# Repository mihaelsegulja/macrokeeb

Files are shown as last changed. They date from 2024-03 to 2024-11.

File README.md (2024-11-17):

# macrokeeb

Simple 10-key Arduino-based macropad with OLED screen and rotary encoder I did for my high school final project.

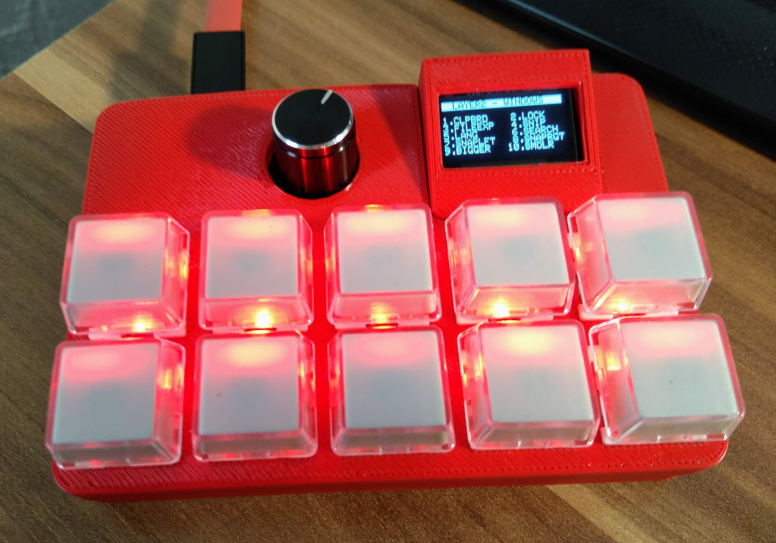
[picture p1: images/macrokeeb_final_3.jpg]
macrokeeb


## Features

- 10 programmable keys
- 5 layers/modes (General, Windows, Linux, VSCode, Other) which can be switched by pressing the button on the rotary encoder
- Rotary encoder knob changes the audio volume
- OLED screen shows current layer and its predefined macros

## Parts

- 1x Arduino Pro Micro
- 1x I2C OLED display, 128x64, 0.96 inch
- 1x Rotary encoder KY-040
- 10x Mechanical switches, red (any Cherry MX compatible will do)
- 10x Keycaps (any Cherry MX compatible will do)
- 10x Standard signal diodes 1N4148
- 10x LED lights, red, 3mm
- Wires (reused from old Christmas lights)
- 3D printed case

### Tools

- 3D printer
- Soldering iron and solder
- Wire cutters
- Hot glue gun
- Sandpaper

## Case

I used the following and modified it a bit (removed the logo, added hex mesh on the side, added hole...):
[CODEK - Configurable OLED Display Extension Keyboard](https://www.thingiverse.com/thing:4539723)

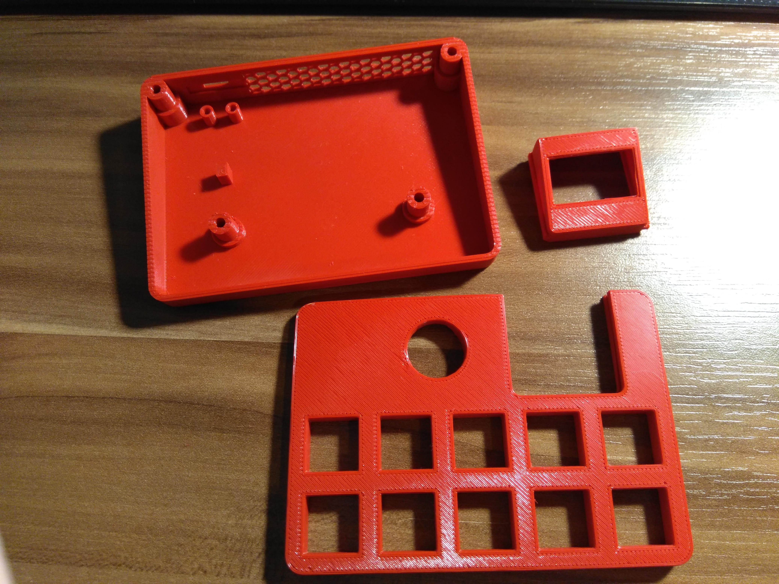
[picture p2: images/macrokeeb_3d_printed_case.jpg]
case


> [!TIP]
> Use sandpaper to smoothen rough edges, read more [here](https://www.3dsourced.com/guides/sanding-pla/) on how to do it.

## Assembly

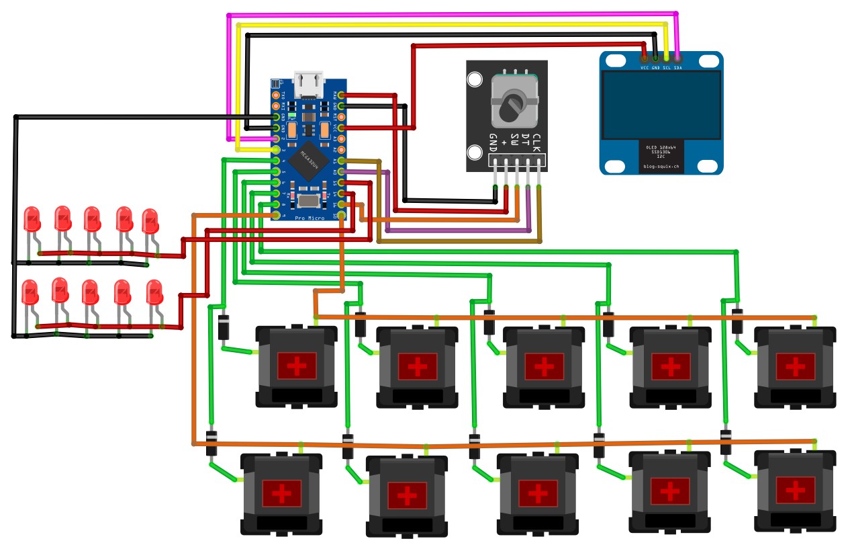
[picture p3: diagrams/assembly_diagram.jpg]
diagram1


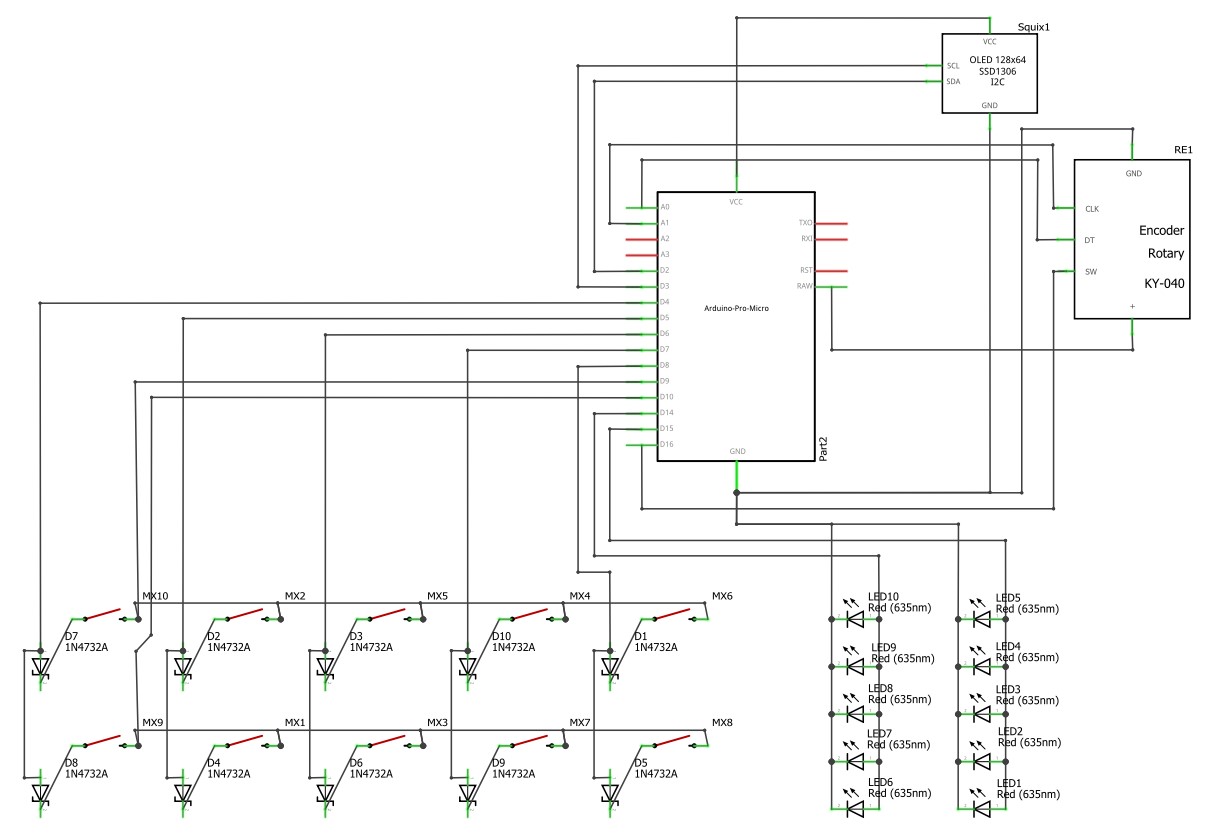
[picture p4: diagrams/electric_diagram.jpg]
diagram2


> [!TIP]
> Before putting it all together, test all of your components separately to ensure they all work.

### Steps

1. Slide the OLED display holder into the top plate. Install the switches into the top plate. Both can be a tight fit, but that shouldn't be a problem. In that case, apply more pressure or sand down the tight parts.

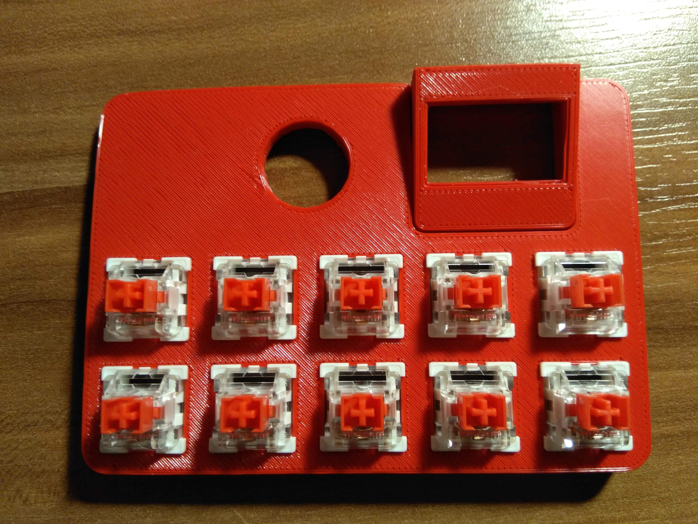
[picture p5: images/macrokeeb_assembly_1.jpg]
step1


2. For wiring, refer to the diagrams. Basically, you have to wire the keys in a matrix. For soldering, I suggest one the following: 
 - cut the wires in smaller ones, long enough to wire up one switch with the next one, 
 - use one wire per row/column and remove the coating where needed,
 - use one wire per row/column and solder through the coating

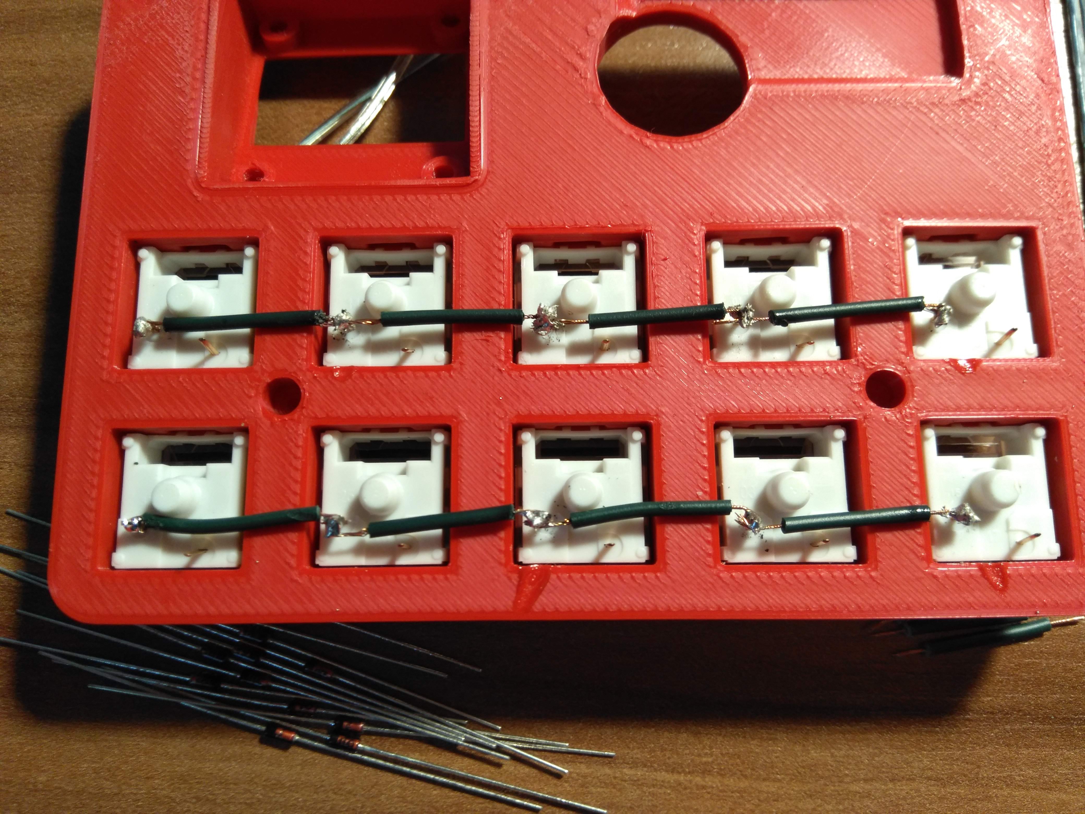
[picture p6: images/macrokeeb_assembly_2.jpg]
step2


3. Add signal diodes on all the keys, it will ensure that the microcotroller doesn't read key presses wrong when pressing several keys at once.

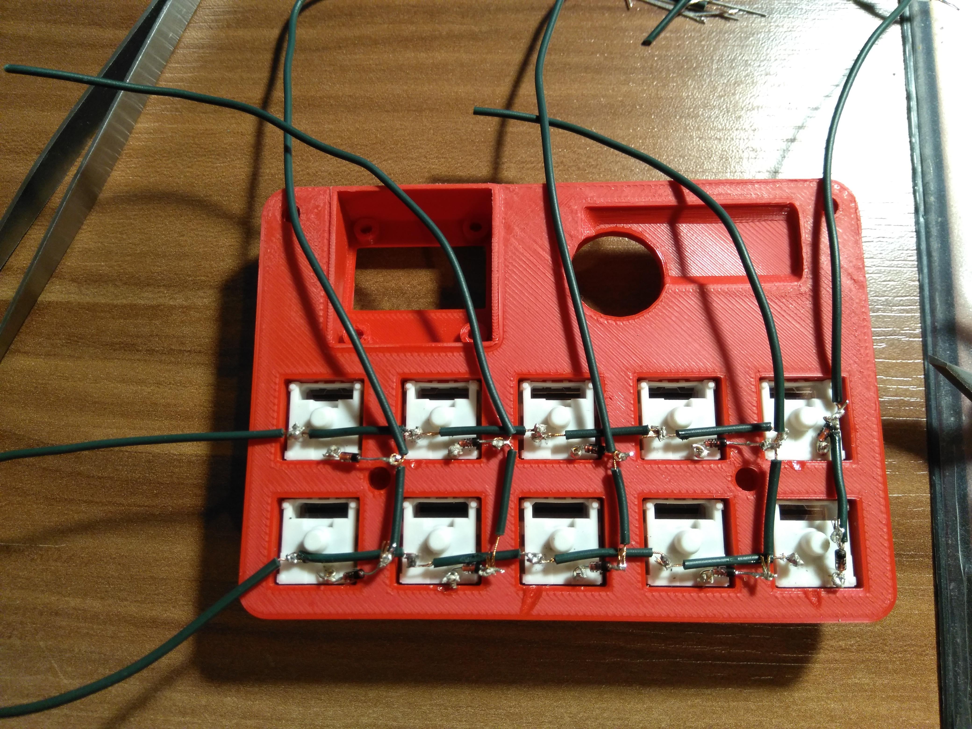
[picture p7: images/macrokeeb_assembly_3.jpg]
step3


4. Adding LEDs is purely for aesthetics.

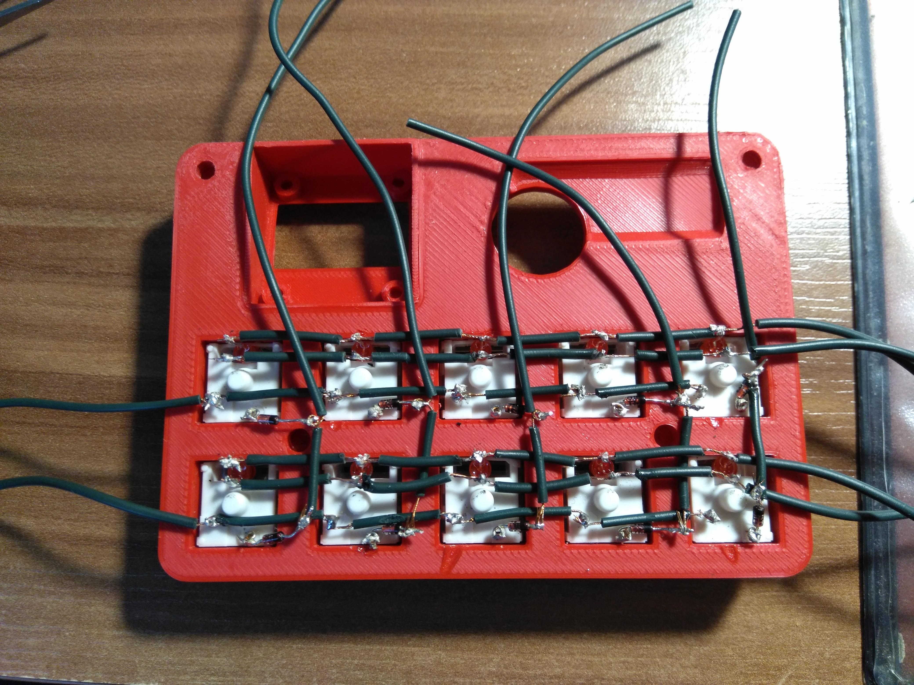
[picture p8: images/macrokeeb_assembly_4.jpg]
step4


5. Solder wires to the OLED display and rotary encoder too.

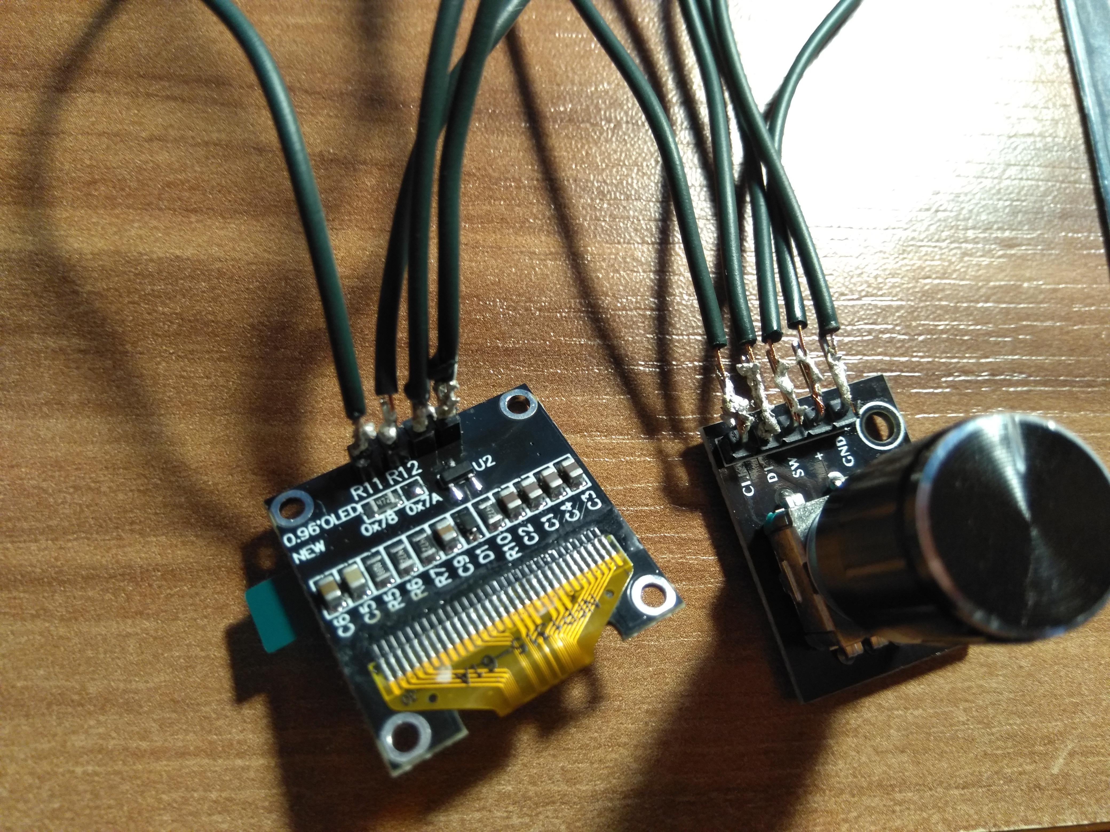
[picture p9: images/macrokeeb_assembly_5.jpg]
step5


6. Solder everything to the Pro Micro.

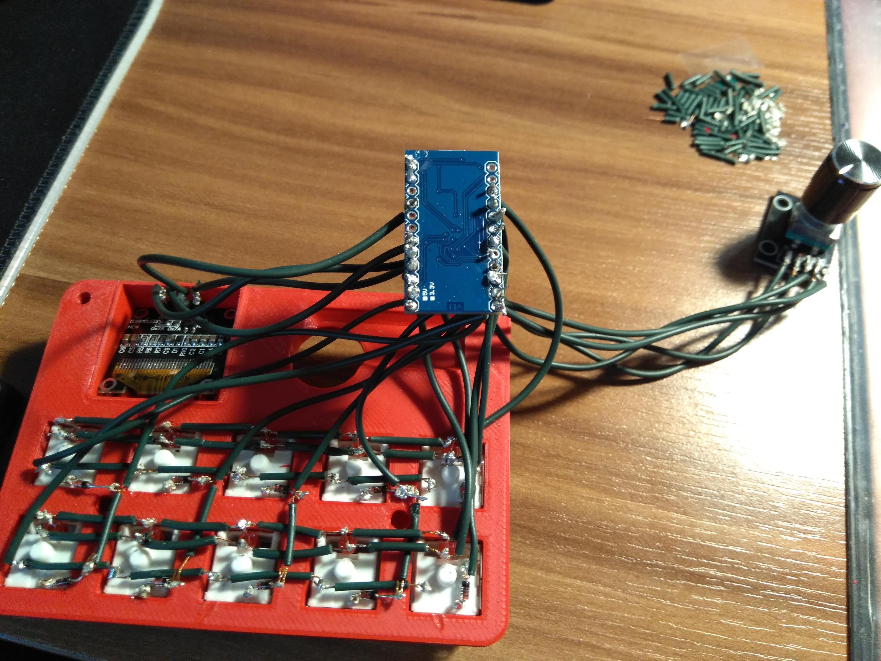
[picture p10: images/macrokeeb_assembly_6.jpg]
step6


7. Now is the time to load the firmware onto the Pro Micro and test it out and make adjustments as needed before closing the case. I used Arduino IDE 2.0. For additional libraries, drivers and their respective guides for installation, refer to the [Links](#links) section.

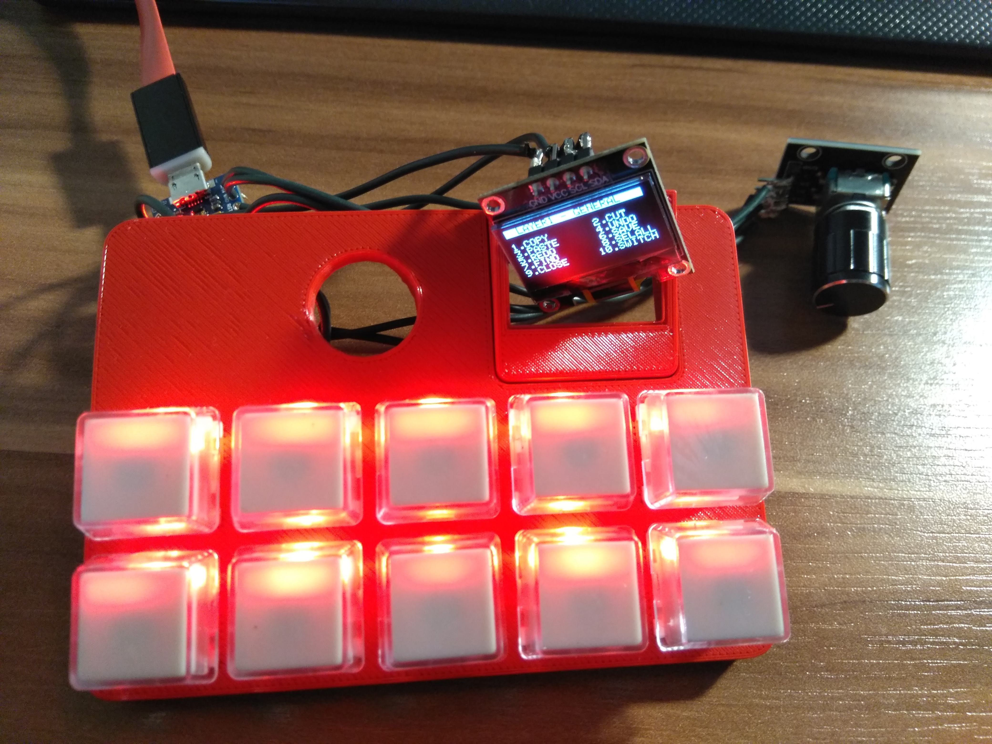
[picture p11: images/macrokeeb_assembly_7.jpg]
step7


8. At last, put hot glue on the LEDs, between the base plate and rotary encoder (make sure it will later fit through the hole), between OLED display and OLED display holder, between the Pro Micro and its holder. Basically, put hot glue on every component/piece that you don't want to hear rattling in the case later.

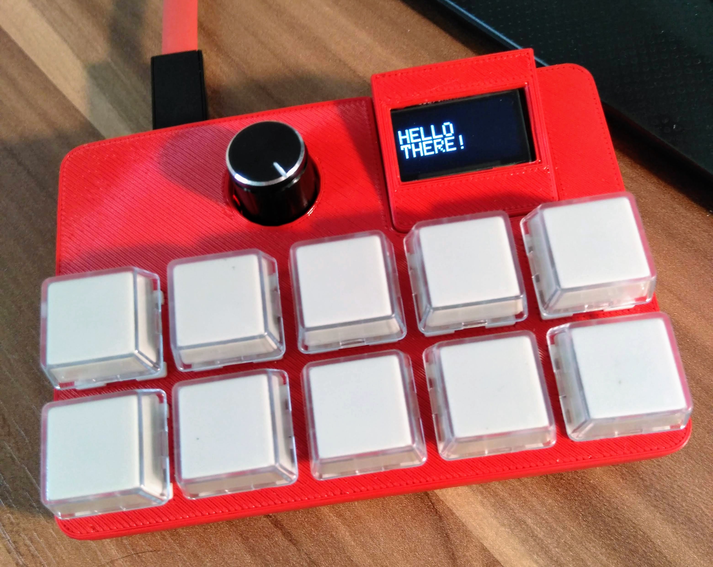
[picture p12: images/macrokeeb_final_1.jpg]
step8


9. That's it! Now take a step back and admire your work.

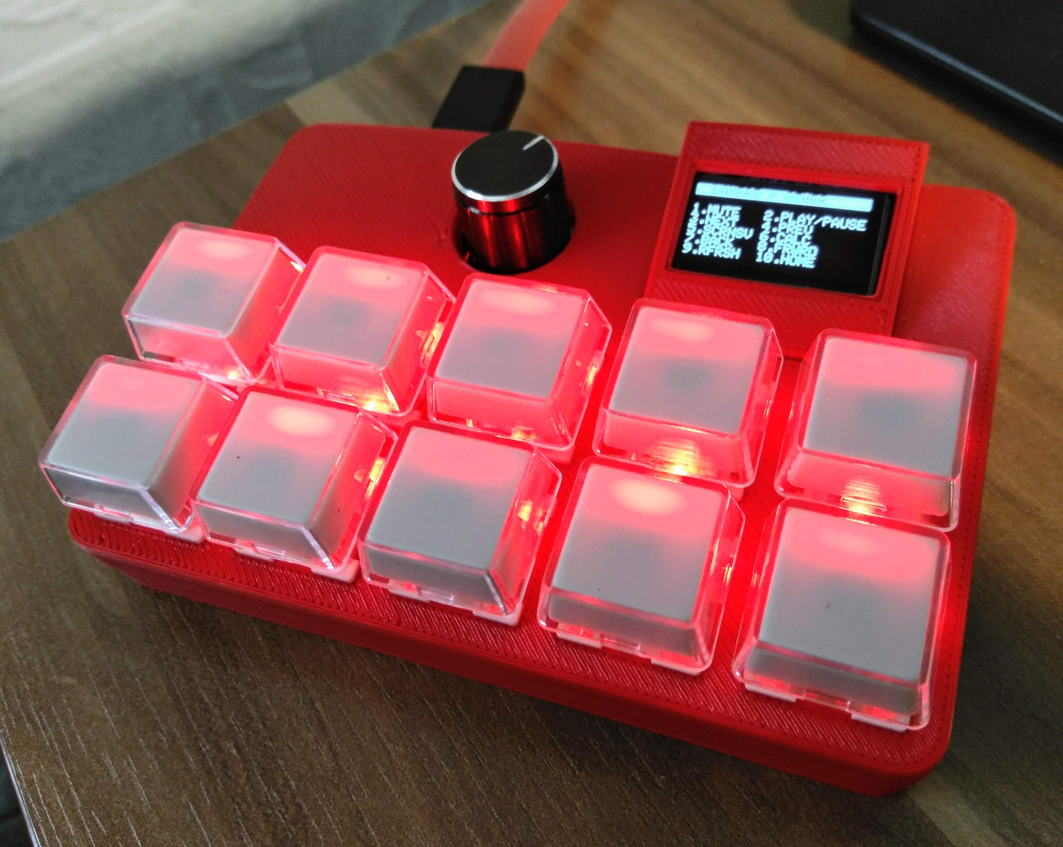
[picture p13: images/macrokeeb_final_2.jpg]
step9


## Suggestions, improvements, ideas

- Add layer with keys F13-F22 and map them with a key mapper software like [AutoHotKey](https://www.autohotkey.com/)
- Add simple games like tetris or pong on the screen and control it with the keys
- Add "gaming" layer where the keys can be w, a, s, d, space etc. and add multi-key press, key press and hold etc.

## Links

- [Pro Micro & Fio V3 Hookup Guide](https://learn.sparkfun.com/tutorials/pro-micro--fio-v3-hookup-guide/all)
- [CODEK - Configurable OLED Display Extension Keyboard](https://www.thingiverse.com/thing:4539723)
- [Programmable Macropad V2](https://www.instructables.com/Programmable-Macropad-V2/)
- [Designing and Building a Macro Pad](https://codevember.org/projects/designing-and-building-a-macro-pad/)
- [Custom Macro Mechanical Keypad](https://www.instructables.com/Custom-Macro-Mechanical-Keypad/)
- [HID library](https://github.com/NicoHood/HID)
- [Adafruit SSD1306 library](https://github.com/adafruit/Adafruit_SSD1306)
- [Adafruit GFX library](https://github.com/adafruit/Adafruit-GFX-Library)

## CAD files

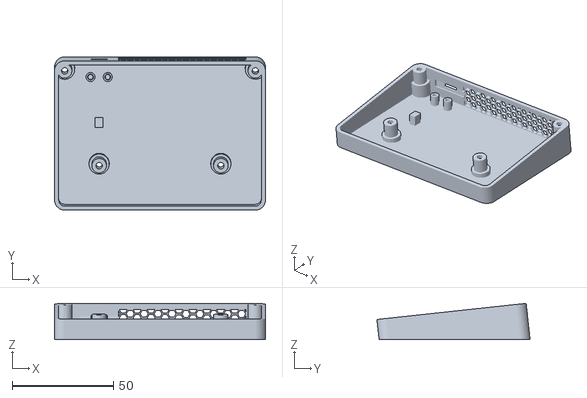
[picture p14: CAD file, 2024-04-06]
3d_models/macrokeeb_base.stl
104.0 x 75.5 x 17.9

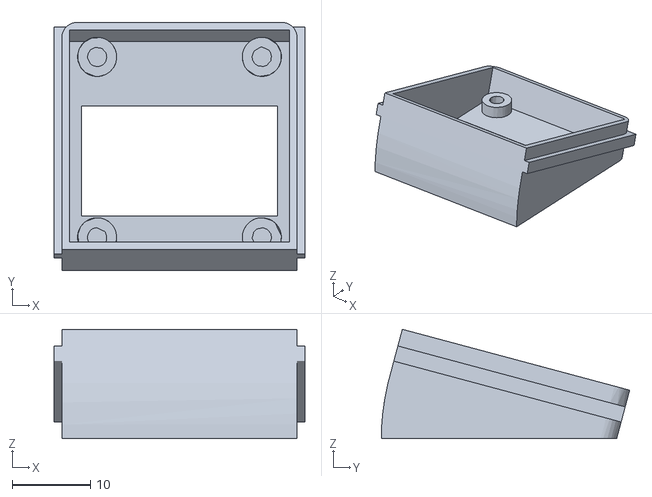
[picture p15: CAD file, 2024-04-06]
3d_models/macrokeeb_display.stl
32.0 x 31.7 x 13.9

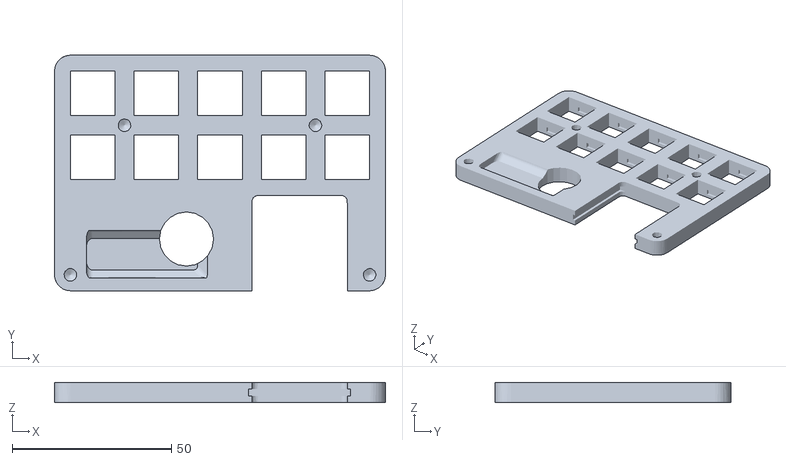
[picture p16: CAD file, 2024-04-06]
3d_models/macrokeeb_top.stl
104.0 x 74.0 x 6.40

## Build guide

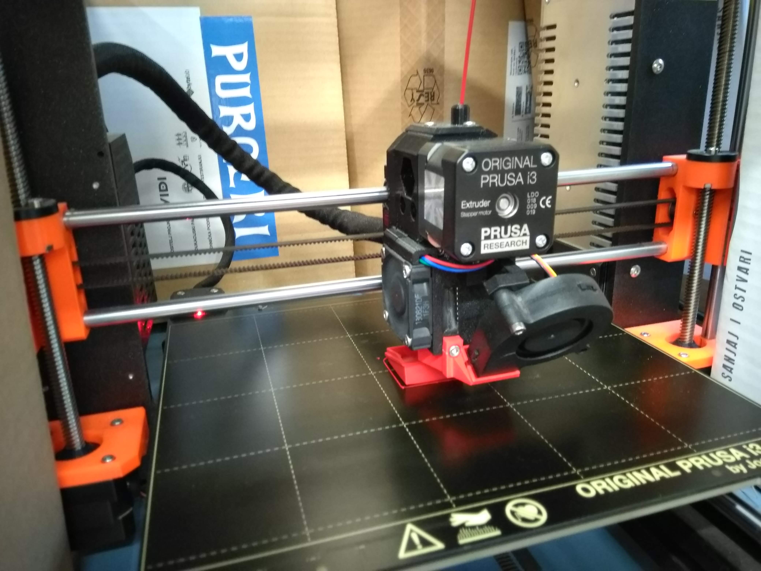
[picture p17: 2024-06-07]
images/macrokeeb_3d_printing_1.jpg

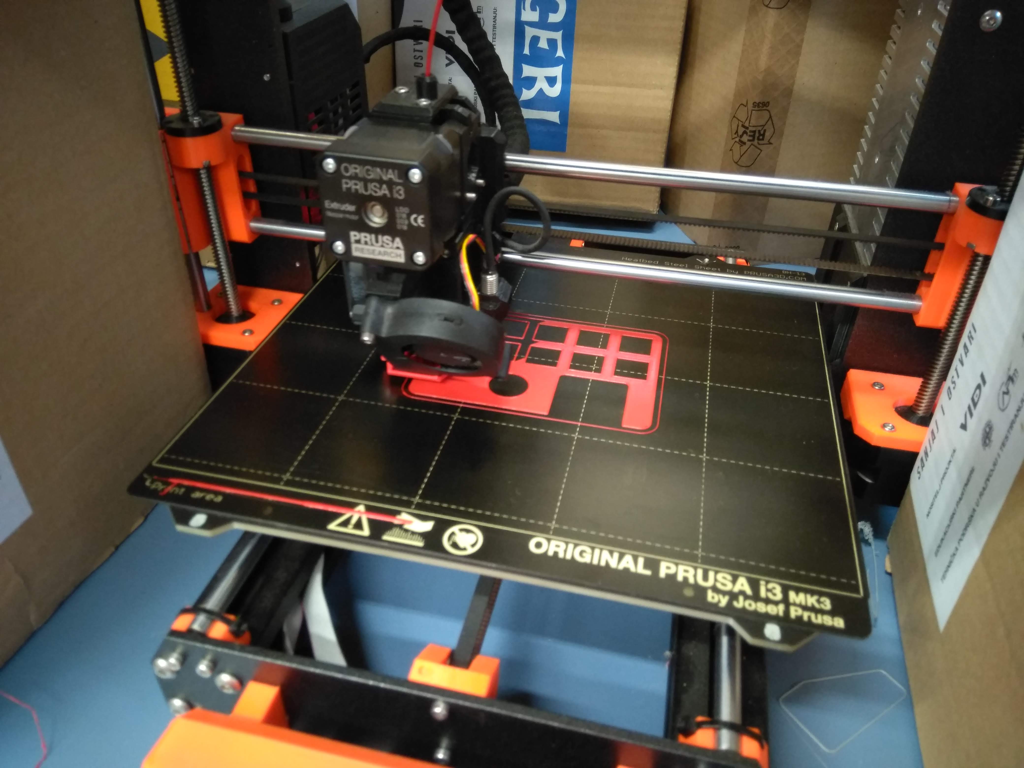
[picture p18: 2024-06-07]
images/macrokeeb_3d_printing_2.jpg

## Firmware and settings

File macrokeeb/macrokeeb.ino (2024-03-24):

#include <Wire.h>
#include <HID-Project.h>
#include <Keypad.h>
#include <Adafruit_GFX.h>
#include <Adafruit_SSD1306.h>
#include <Encoder.h>

const byte ROWS = 2;
const byte COLS = 5;
char keys[ROWS][COLS] = {
  {'1','2','3','4','5'},
  {'6','7','8','9','0'} 
};
byte rowPins[ROWS] = {10, 9};
byte colPins[COLS] = {4, 5, 6, 7, 8};
Keypad kpd = Keypad( makeKeymap(keys), rowPins, colPins, ROWS, COLS);

#define CLK 19    // A1
#define DT 18     // A0
#define SW 16
Encoder enc(DT, CLK);

long oldPosition  = -999;
byte counterSW = 1;
int lastButtonPress = 0;

Adafruit_SSD1306 display(128, 64, &Wire, -1);

void setup() {
  Serial.begin(9600);
  pinMode(14, OUTPUT);
  pinMode(15, OUTPUT);
  pinMode(SW, INPUT_PULLUP);
  
  if(!display.begin(SSD1306_SWITCHCAPVCC, 0x3C)){
    Serial.println(F("SSD1306 allocation failed"));
    for(;;);
  }

  // splash screen
  display.display();
  display.clearDisplay();
  display.setCursor(0,0);
  display.setTextSize(2);
  display.setTextColor(WHITE);
  display.println();
  display.println("HELLO");
  display.println("THERE!");
  display.display();
  display.startscrollright(0x00, 0x0F);
  delay(5000);
  display.stopscroll();

  Consumer.begin();
  Keyboard.begin();
}

void loop() {
  // LED lights
  digitalWrite(14, HIGH);
  digitalWrite(15, HIGH);

  long newPosition = enc.read();
  
  // volume control with rotary encoder
  if(newPosition != oldPosition){
    if(newPosition - oldPosition > 0){
      Consumer.write(MEDIA_VOLUME_UP);
    }
    else{
      Consumer.write(MEDIA_VOLUME_DOWN);
    }
      oldPosition = newPosition;
      delay(5);
  }

  int btnState = digitalRead(SW);

  if(btnState == LOW){
    if(millis() - lastButtonPress > 50){
      counterSW++;
      delay(300);
    }
    lastButtonPress = millis();
  }

  if(counterSW > 5){
    counterSW = 1;
  }

  oledOutput(counterSW);

  char key = kpd.getKey();

  // layer switcher
  if(key){
    switch(counterSW){
      case 1: layer1(key); break;
      case 2: layer2(key); break;
      case 3: layer3(key); break;
      case 4: layer4(key); break;
      case 5: layer5(key); break;
    }
  }

  delay(10);
  
  Consumer.releaseAll();
  Keyboard.releaseAll();
}

// functions layer1() - layer5()
// for every physical button pressed, one or more keys are activated (macro command)
// for example, if we press key 1, key CTRL and key C will be pressed
void layer1(char key){
  switch(key){
    case '1': 
      Keyboard.press(KEY_LEFT_CTRL); 
      Keyboard.press(KEY_C); 
      break;
    case '2': 
      Keyboard.press(KEY_LEFT_CTRL); 
      Keyboard.press(KEY_X); 
      break;
    case '3': 
      Keyboard.press(KEY_LEFT_CTRL); 
      Keyboard.press(KEY_V); 
      break;
    case '4': 
      Keyboard.press(KEY_LEFT_CTRL); 
      Keyboard.press(KEY_Z); 
      break;
    case '5': 
      Keyboard.press(KEY_LEFT_CTRL); 
      Keyboard.press(KEY_Y); 
      break;
    case '6': 
      Keyboard.press(KEY_LEFT_CTRL); 
      Keyboard.press(KEY_S); 
      break;
    case '7': 
      Keyboard.press(KEY_LEFT_CTRL);
      Keyboard.press(KEY_F); 
      break;
    case '8': 
      Keyboard.press(KEY_LEFT_CTRL); 
      Keyboard.press(KEY_A); 
      break;
    case '9': 
      Keyboard.press(KEY_LEFT_ALT); 
      Keyboard.press(KEY_F4); 
      break;
    case '0': 
      Keyboard.press(KEY_LEFT_WINDOWS); 
      Keyboard.press(KEY_TAB); 
      break;
  }
}

void layer2(char key){      
  switch(key){
    case '1': 
      Keyboard.press(KEY_LEFT_WINDOWS); 
      Keyboard.press(KEY_V); 
      break;
    case '2': 
      Keyboard.press(KEY_LEFT_WINDOWS); 
      Keyboard.press(KEY_L); 
      break;
    case '3': 
      Keyboard.press(KEY_LEFT_WINDOWS); 
      Keyboard.press(KEY_E); 
      break;
    case '4': 
      Keyboard.press(KEY_LEFT_WINDOWS); 
      Keyboard.press(KEY_LEFT_SHIFT); 
      Keyboard.press(KEY_S); 
      break;
    case '5': 
      Keyboard.press(KEY_LEFT_WINDOWS); 
      Keyboard.press(KEY_SPACE); 
      break;
    case '6': 
      Keyboard.press(KEY_LEFT_WINDOWS); 
      Keyboard.press(KEY_S); 
      break;
    case '7': 
      Keyboard.press(KEY_LEFT_WINDOWS); 
      Keyboard.press(KEY_LEFT_ARROW); 
      break;
    case '8': 
      Keyboard.press(KEY_LEFT_WINDOWS); 
      Keyboard.press(KEY_RIGHT_ARROW); 
      break;
    case '9': 
      Keyboard.press(KEY_LEFT_WINDOWS); 
      Keyboard.press(KEY_UP_ARROW); 
      break;
    case '0': 
      Keyboard.press(KEY_LEFT_WINDOWS); 
      Keyboard.press(KEY_DOWN_ARROW); 
      break;
  }
}

void layer3(char key){      
  switch(key){
    case '1': 
      Keyboard.press(KEY_LEFT_ALT); 
      Keyboard.press(KEY_F2); 
      break;
    case '2': 
      Keyboard.press(KEY_LEFT_CTRL); 
      Keyboard.press(KEY_LEFT_ALT); 
      Keyboard.press(KEY_L); 
      break;
    case '3': 
      Keyboard.press(KEY_LEFT_CTRL); 
      Keyboard.press(KEY_LEFT_ALT); 
      Keyboard.press(KEY_F1); 
      break;
    case '4': 
      Keyboard.press(KEY_LEFT_CTRL); 
      Keyboard.press(KEY_LEFT_ALT); 
      Keyboard.press(KEY_F7); 
      break;
    case '5': 
      Keyboard.press(KEY_LEFT_CTRL); 
      Keyboard.press(KEY_L); 
      break;
    case '6': 
      Keyboard.press(KEY_LEFT_CTRL); 
      Keyboard.press(KEY_U); 
      break;
    case '7': 
      Keyboard.press(KEY_LEFT_CTRL); 
      Keyboard.press(KEY_A); 
      break;
    case '8': 
      Keyboard.press(KEY_LEFT_CTRL); 
      Keyboard.press(KEY_E); 
      break;
    case '9': 
      Keyboard.press(KEY_LEFT_CTRL); 
      Keyboard.press(KEY_LEFT_SHIFT); 
      Keyboard.press(KEY_C); 
      break;
    case '0': 
      Keyboard.press(KEY_LEFT_CTRL); 
      Keyboard.press(KEY_LEFT_SHIFT); 
      Keyboard.press(KEY_V); 
      break;
  }
}

void layer4(char key){      
  switch(key){
    case '1': 
      Keyboard.press(KEY_F1); 
      break;
    case '2': 
      Keyboard.press(KEY_LEFT_SHIFT); 
      Keyboard.press(KEY_F6); 
      break;
    case '3': 
      Keyboard.press(KEY_LEFT_ALT); 
      Keyboard.press(KEY_DOWN_ARROW); 
      break;
    case '4': 
      Keyboard.press(KEY_LEFT_ALT); 
      Keyboard.press(KEY_UP_ARROW); 
      break;
    case '5': 
      Keyboard.press(KEY_LEFT_CTRL); 
      Keyboard.press(KEY_O); 
      break;
    case '6': 
      Keyboard.press(KEY_LEFT_CTRL); 
      Keyboard.press(KEY_LEFT_SHIFT); 
      Keyboard.press(KEY_K); 
      break;
    case '7': 
      Keyboard.press(KEY_LEFT_ALT); 
      Keyboard.press(KEY_L); 
      Keyboard.press(KEY_O); 
      break;
    case '8': 
      Keyboard.press(KEY_LEFT_ALT); 
      Keyboard.press(KEY_L); 
      Keyboard.press(KEY_C); 
      break;
    case '9': 
      Keyboard.press(KEY_LEFT_CTRL); 
      Keyboard.press(KEY_LEFT_ALT); 
      Keyboard.press(KEY_N); 
      break;
    case '0': 
      Keyboard.press(KEY_LEFT_CTRL); 
      Keyboard.press(KEY_K); 
      Keyboard.press(KEY_O); 
      break;
  }
}

void layer5(char key){      
  switch(key){
    case '1': 
      Consumer.write(MEDIA_VOLUME_MUTE); 
      break;
    case '2': 
      Consumer.write(MEDIA_PLAY_PAUSE); 
      break;
    case '3': 
      Consumer.write(MEDIA_NEXT); 
      break;
    case '4': 
      Consumer.write(MEDIA_PREVIOUS); 
      break;
    case '5': 
      Consumer.write(CONSUMER_SCREENSAVER); 
      break;
    case '6': 
      Consumer.write(CONSUMER_CALCULATOR); 
      break;
    case '7': 
      Consumer.write(CONSUMER_BROWSER_BACK); 
      break;
    case '8': 
      Consumer.write(CONSUMER_BROWSER_FORWARD); 
      break;
    case '9': 
      Consumer.write(CONSUMER_BROWSER_REFRESH); 
      break;
    case '0': 
      Consumer.write(CONSUMER_BROWSER_HOME); 
      break;
  }
}

// function for output on OLED display
// outputs current layer and short name of macro
void oledOutput(byte counterSW){
  display.clearDisplay();
  display.setTextSize(1);
  display.setTextColor(BLACK, WHITE);
  display.setCursor(0,0);
  switch(counterSW){
    case 1: 
      display.println("  LAYER1 - GENERAL   ");
      display.setTextColor(WHITE);
      display.println();
      display.println("1.COPY       2.CUT");
      display.println("3.PASTE      4.UNDO");
      display.println("5.REDO       6.SAVE");
      display.println("7.FIND       8.SELALL");
      display.println("9.CLOSE     10.SWITCH");
      display.display();
      break;
    case 2:
      display.println("  LAYER2 - WINDOWS   ");
      display.setTextColor(WHITE);
      display.println();
      display.println("1.CLPBRD    2.LOCK");
      display.println("3.FILEEXP   4.SNIP");
      display.println("5.LANG      6.SEARCH");
      display.println("7.SNAPLFT   8.SNAPRGT");
      display.println("9.BIGGER   10.SMOLR");
      display.display();
      break;
    case 3: 
      display.println("  LAYER3 - LINUX     ");
      display.setTextColor(WHITE);
      display.println();
      display.println("1.CMDLNCHR  2.LOCK");
      display.println("3.VTY1      4.GUI");
      display.println("5.CLEAR     6.ERASELN");
      display.println("7.BEGINLN   8.ENDLN");
      display.println("9.COPY      10.PASTE");
      display.display();
      break;
    case 4:
      display.println("  LAYER4 - VSCODE    ");
      display.setTextColor(WHITE);
      display.println();
      display.println("1.CMDPLT   2.OPNINBRW");
      display.println("3.MVLNDWN  4.MVLNUP");
      display.println("5.OPENFILE 6.DELLN");
      display.println("7.LIVESVR  8.CLIVESVR");
      display.println("9.RUNCODE  10.OPNFLDR");
      display.display();
      break;
    case 5:
      display.println("  LAYER5 - OTHER     ");
      display.setTextColor(WHITE);
      display.println();
      display.println("1.MUTE   2.PLAY/PAUSE");
      display.println("3.NEXT   4.PREV");
      display.println("5.SCRNSV 6.CALC");
      display.println("7.BACK   8.FRWRD");
      display.println("9.RFRSH  10.HOME");
      display.display();
      break;      
  }
}
